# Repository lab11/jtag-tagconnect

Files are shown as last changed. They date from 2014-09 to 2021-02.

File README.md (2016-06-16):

JTAG to Tag Connect
===================

This PCB is an adapter that converts the [20 pin JLink](https://www.segger.com/jlink-debug-probes.html) connector to
a [6-pin Tag Connect](http://www.tag-connect.com/TC2030-IDC-NL),
much like [this](https://www.segger.com/jlink-6-pin-adapter.html) board.
Ours, however, additionally contains an onboard LDO
that can supply 3.3V to the attached device and the VTRef pin on the J-Link programmer
so that it can program boards that are not self powered.

Interface
---------

- **Switch 1**, labeled `VREF`: Set to `3V3` to connect the `VCC` pin on the TagConnect
header (and the attached board to be programmed) and the `VTRef` pin from
the Segger JLink to the 3.3 V output from the regulator.
Set to `DEV` to directly connect the `VTRef` pin on the JLink to the TagConnect
VCC pin. This sets the I/O voltage for the JLink, but does not power the target board.

- **Switch 2**, labeled `SWDIO`: This switch can connect the `SWDIO` and
`!RESET` signals, which is needed on some ICs. To leave the signals
disconnected, leave the switch in the empty (down) position.

Troubleshooting
---------------

1. Blue LED does not come on when attached to JLink.
You need to enable the 5 V output on the JLink:

        $ JlinkExe
        power on perm

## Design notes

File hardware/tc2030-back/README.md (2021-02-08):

# Tag Connect Clip Back

This is as replica / replacement for https://www.tag-connect.com/wp-content/uploads/bsk-pdf-manager/TC2030-CLIP_Datasheet_24.pdf

In addition to these boards, you'll need recepticle pins https://www.digikey.com/en/products/detail/mill-max-manufacturing-corp/0295-0-15-01-06-27-10-0/158170

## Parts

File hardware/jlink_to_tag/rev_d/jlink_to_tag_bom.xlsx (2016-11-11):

Qty | Value | Device | Package | Parts | Description | DIGIKEY
1 | 10nF | CAPACITOR0603_CAP | 0603_CAP | C1 | 0402 Capacitor | 490-1512-1-ND
2 | 4.7uF | CAPACITOR0603_CAP | 0603_CAP | C2, C3 | 0402 Capacitor | 490-3297-1-ND
9 | BLUE | LED-BLUE0603 | LED-0603 | D1, D2, D3, D4, D5, D6, D7, D8, D9 | Blue LEDs
1 |  | ML20 | ML20 | J1 | HARTING | S9172-ND
8 | JLINK_6PIN_TAG-CON | JLINK_6PIN_TAG-CON | 2X3_MALE_SHROUDED_0.100 | J2, J3, J4, J5, J6, J7, J8, J9 | This is a 6-pin Tag Connect header with the J-Link. | 3M15451-ND
1 |  | PINHD-2X3 | 2X03 | J10 | PIN HEADER
9 | 470 | RESISTOR0603-RES | 0603-RES | R1, R2, R3, R4, R5, R6, R7, R8, R9 | Resistor
7 | 1k | RESISTOR0603-RES | 0603-RES | R10, R11, R12, R13, R14, R15, R16 | Resistor | RHM1.00KHCT-ND
8 | PTS645SM43SMTR92 | PTS645SM43SMTR92 | PTS645 | S1, S2, S3, S4, S5, S6, S7, S8 | Tactile Switch SPST-NO Top Actuated Surface Mount | CKN9112CT-ND
1 | RM100772BCB | RM100772BCB | RM-SWITCH | S9 | Rotary Switch 8 Position SP7T 500mA (DC) 24VDC Through Hole | CKN10691-ND
8 | SN74AHC4066-RGY | SN74AHC4066-RGY | S-PVQFN-N14-3.5MM | S10, S11, S12, S13, S14, S15, S16, S17 |  | 296-15258-1-ND
2 | STS121PC04 | STS121PC04 | STS121PC04 | S18, S19 | Slide Switch SPDT Through Hole | 450-1609-ND
1 | 74HC4002PW | 74HC4002PW | TSSOP-14/5MM | U1 | NOR Gate IC 2 Channel 14-TSSOP | 568-8879-1-ND
1 | MAX8887EZK33+T | MAX8887EZK33+T | SOT-23-5 | U2 | IC REG LDO 3.3V 0.3A TSOT23-5 | MAX8887EZK33+TCT-ND

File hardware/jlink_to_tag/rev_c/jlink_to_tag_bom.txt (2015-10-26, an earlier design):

# Bill of Materials
# Converted from jlink_to_tag_bom.xlsx
# Generated by bom_to_text.py

Qty  Value               Device              Package                  Parts   Description                                          DIGIKEY
2    0.01uF              C-EUC0603           C0603                    C1, C2  CAPACITOR, European symbol                           490-1512-1-ND
1    10uF                CAP_POL1206         EIA3216                  C3      Capacitor Polarized                                  399-3684-1-ND
1    BLUE                LED-BLUE0603        LED-0603                 D1      Blue LEDs for production use                         
1                        ML20                ML20                     J1      HARTING                                              S9172-ND
1    JLINK_6PIN_TAG-CON  JLINK_6PIN_TAG-CON  2X3_MALE_SHROUDED_0.100  J2      This is a 6-pin Tag Connect header with the J-Link.  3M15451-ND
1    470                 RESISTOR0603-RES    0603-RES                 R1      Resistor                                             
1    EVQP2               EVQP2               EVQP2                    S1      SWITCH TACTILE SPST-NO 0.02A 15V                     P11084SCT-ND
2    TE_SSA12/SPDT       TE_SSA12/SPDT       TE_SSA12/SPDT            S2, S3  SWITCH SLIDE SPDT 2POS SSA SER                       450-1602-ND
1    LT1763CS8-3.3       LT1763CS8-3.3       SOIC8                    U1      500mA, Low Noise, LDO Micropower Regulators          LT1763CS8-3.3#TRPBFCT-ND

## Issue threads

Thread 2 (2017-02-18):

revD issues

ppannuto, 2017-02-18:
- [ ] active channel LEDs are too close to shrouded headers, hard to see, should move more towards the center of the board
 - [ ] reset buttons don't work if j-link isn't attached

ppannuto, 2017-02-18:
- [ ] board name isn't on board anywhere (which makes finding the appropriate repo an annoying game)

ppannuto, 2017-06-26:
- [ ] Center switch numbering is opposite of the external numbering (i.e. turning the switch counter-clockwise moves a slot forward clockwise)

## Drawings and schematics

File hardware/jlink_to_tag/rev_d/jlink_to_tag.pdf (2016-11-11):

# 20-Pin Ribbon Cable from JLink

# 6 Pin Pogo Connector

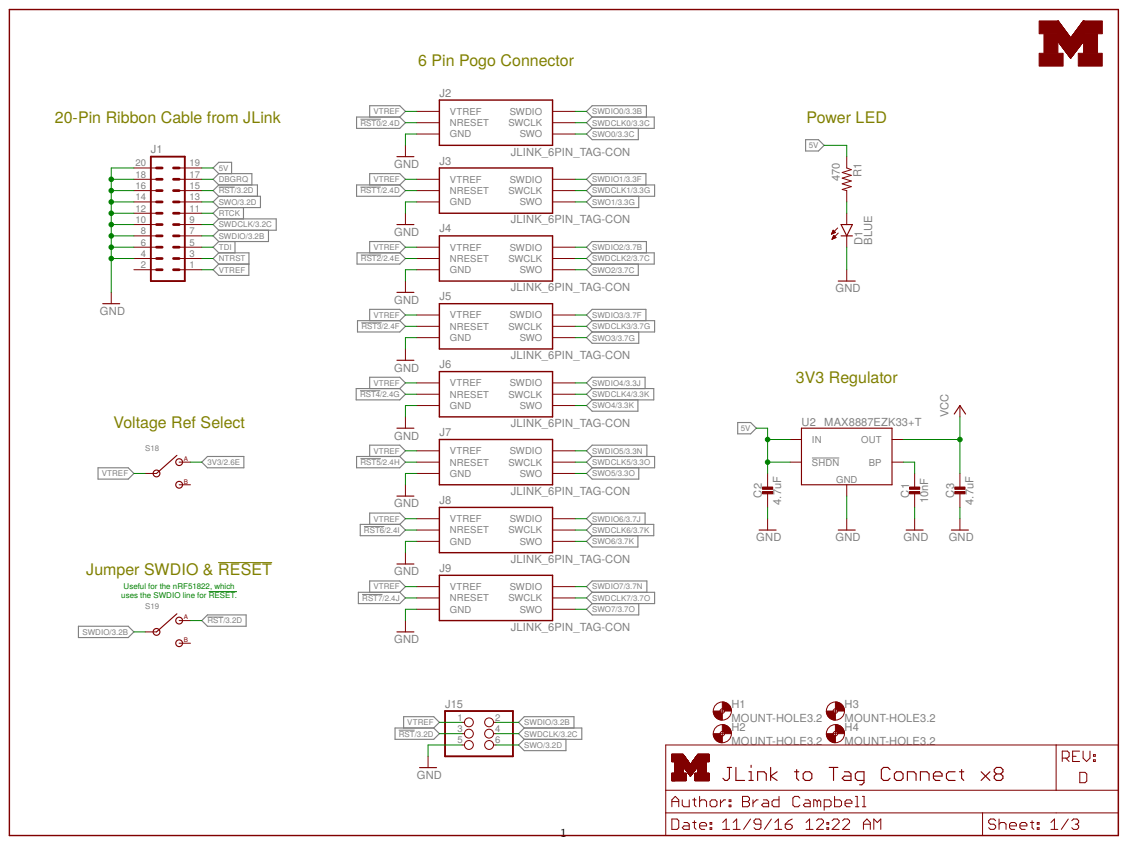
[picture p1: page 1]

Useful for the nRF51822, which
uses the SWDIO line for RESET.

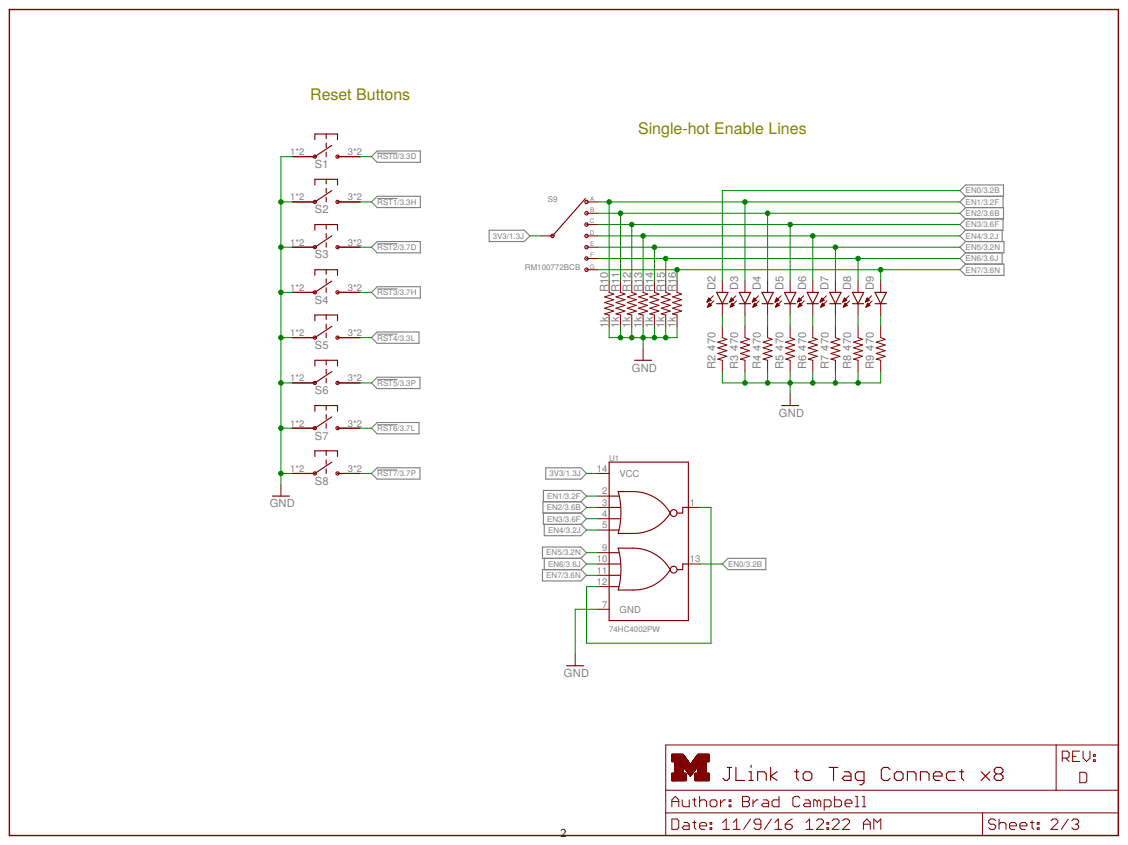
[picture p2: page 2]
Single-hot Enable Lines Reset Buttons GND; RM100772BCB; 1k1k1k1k1k1k1k GND; 470 470 470 470 470 470 470 470 GND 74HC4002PW GND S1 ¹*2; ABCD S9; EFG R¹⁰ R¹¹ R¹² R¹³ R¹⁴ R¹⁵ R¹⁶; 13 VCC 14; GND 7 U1 RST0/3.3D RST1/3.3H RST2/3.7D RST3/3.7H RST4/3.3L RST5/3.3P RST6/3.7L RST7/3.7P

# Tag Connect Port Enable Circuits

## GND

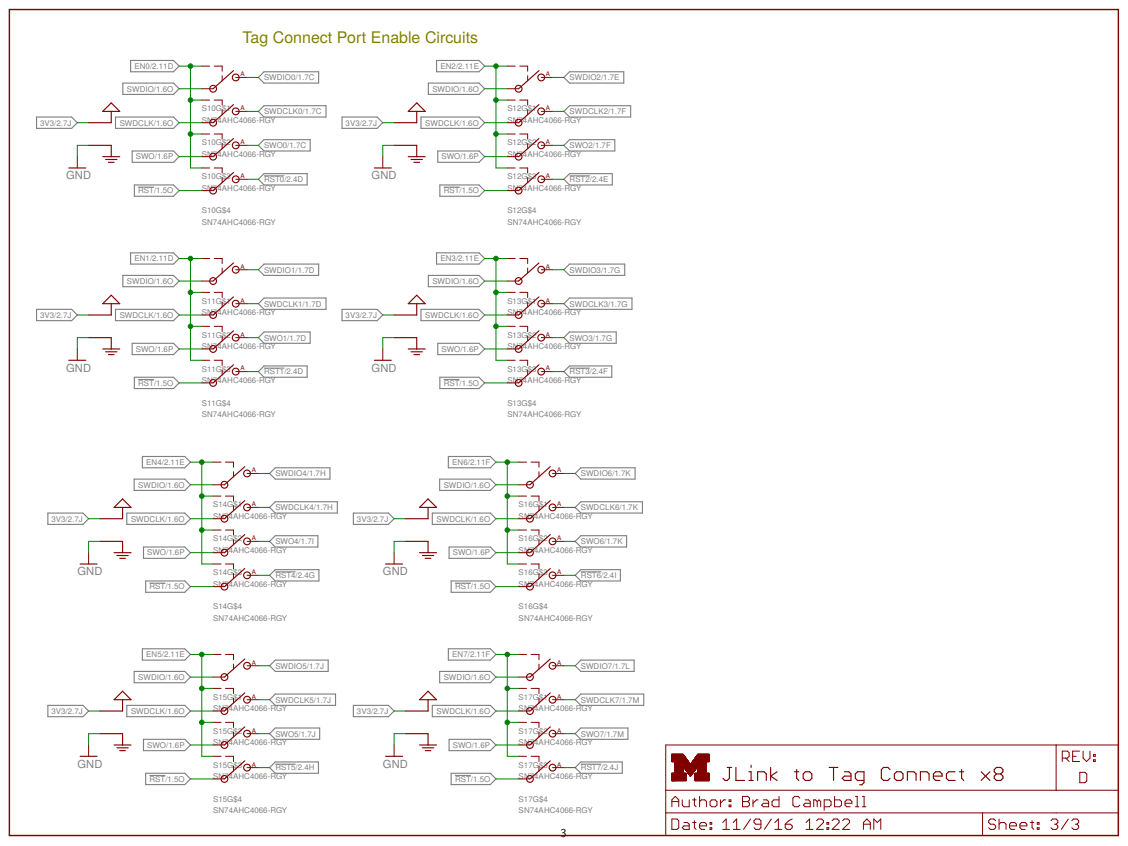
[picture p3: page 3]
SN74AHC4066-RGY; GND; SWDCLK/1.6O; SWO/1.6P; RST/1.5O; RST0/2.4D; SWO0/1.7C; SWDIO0/1.7C; SWDCLK0/1.7C; SWDIO/1.6O; RST1/2.4D; SWO1/1.7D; SWDCLK1/1.7D; SWDIO1/1.7D; SWDIO2/1.7E; SWDCLK2/1.7F SWO2/1.7F RST2/2.4E; SWDIO3/1.7G; SWDCLK3/1.7G; SWO3/1.7G; RST3/2.4F; SWDIO4/1.7H; SWDCLK4/1.7H; SWO4/1.7I RST4/2.4G; SWDIO5/1.7J SWDCLK5/1.7J SWO5/1.7J RST5/2.4H; SWDIO6/1.7K; SWDCLK6/1.7K; SWO6/1.7K RST6/2.4I; SWDIO7/1.7L SWDCLK7/1.7M; SWO7/1.7M; RST7/2.4J

### Top and Bottom Layers

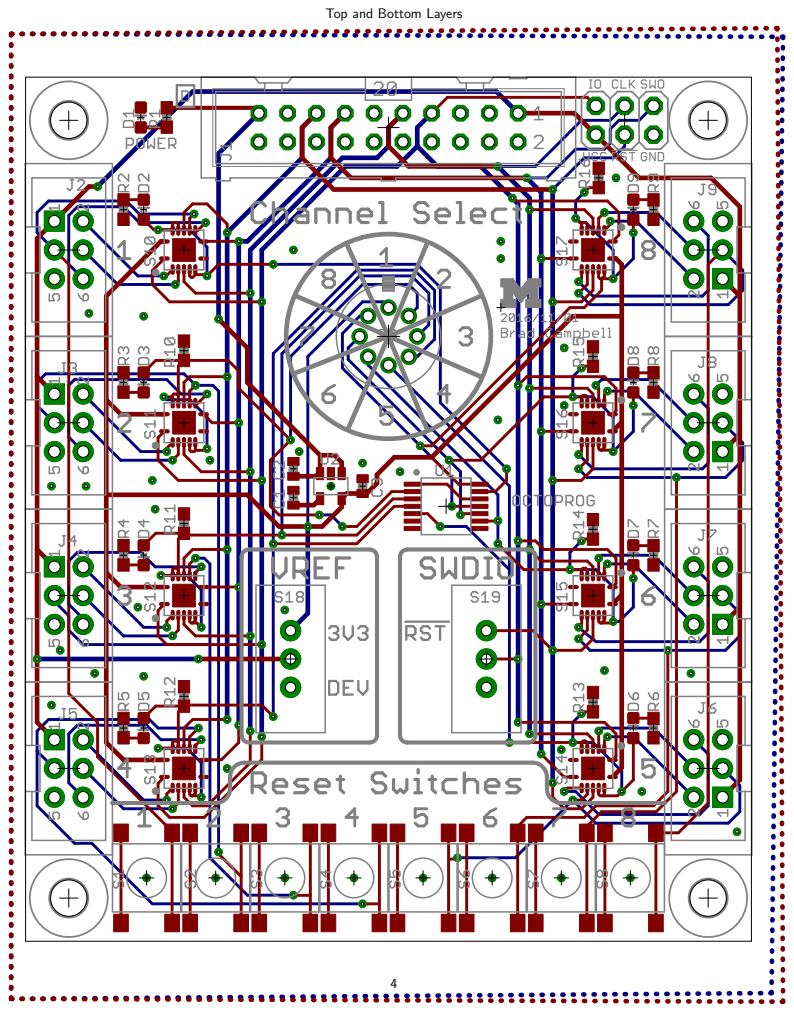
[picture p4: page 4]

### Top Layer

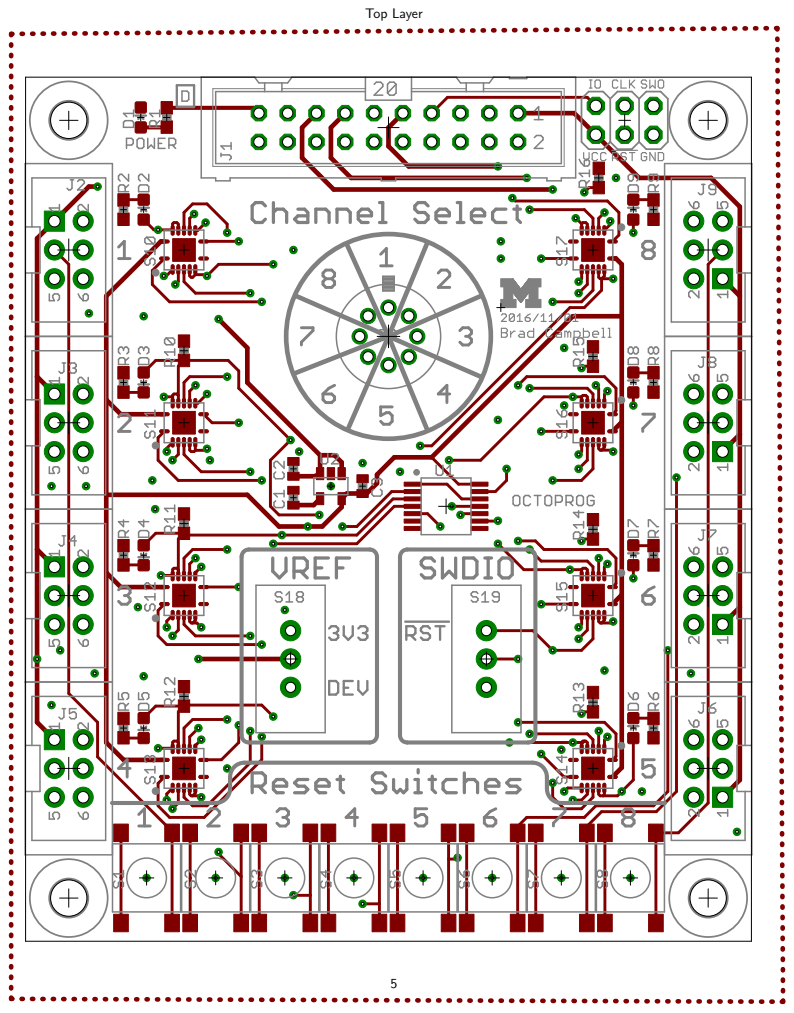
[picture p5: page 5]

### Bottom Layer

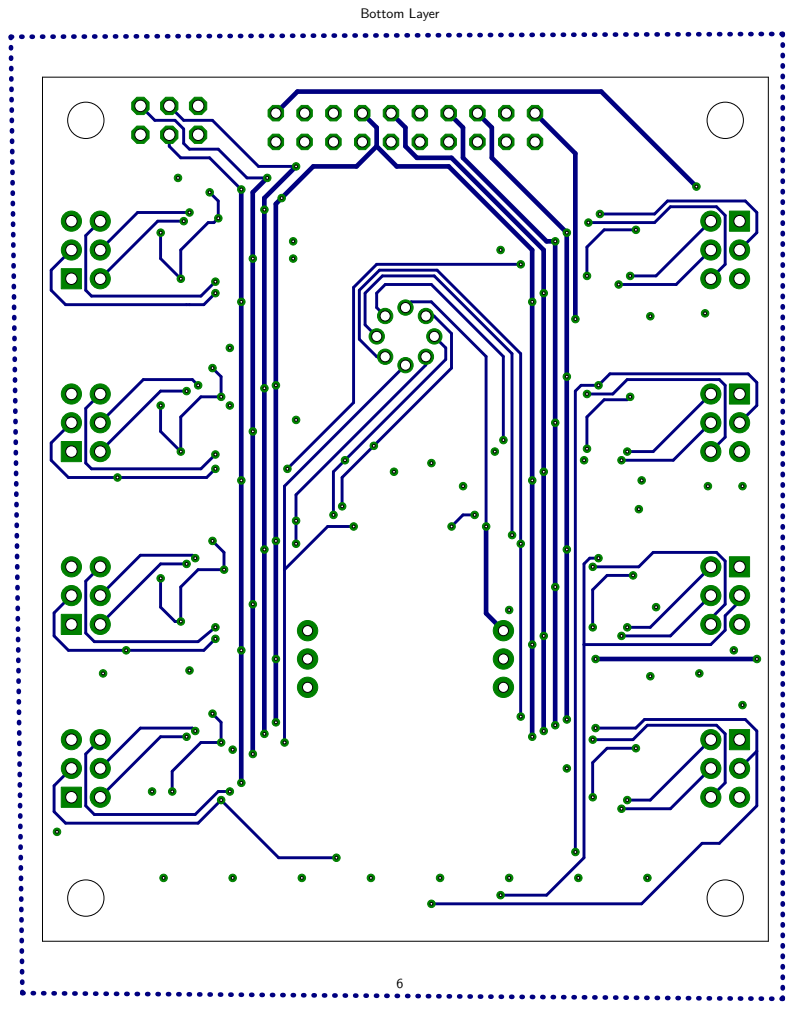
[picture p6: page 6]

### Top Copper Layer

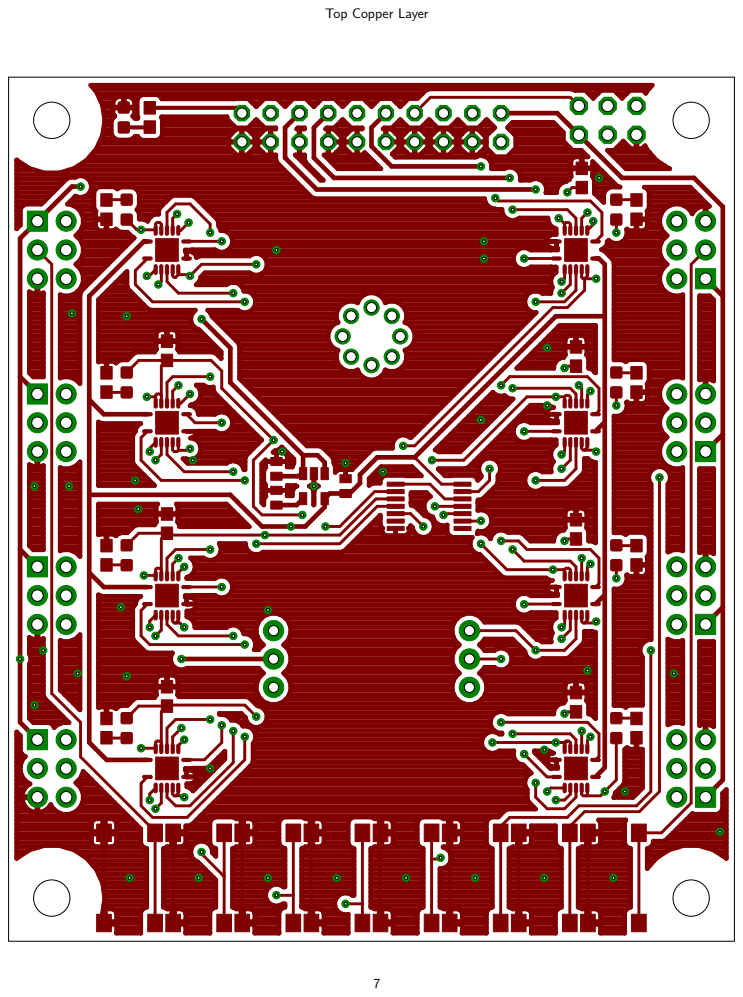
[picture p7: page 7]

### Bottom Copper Layer

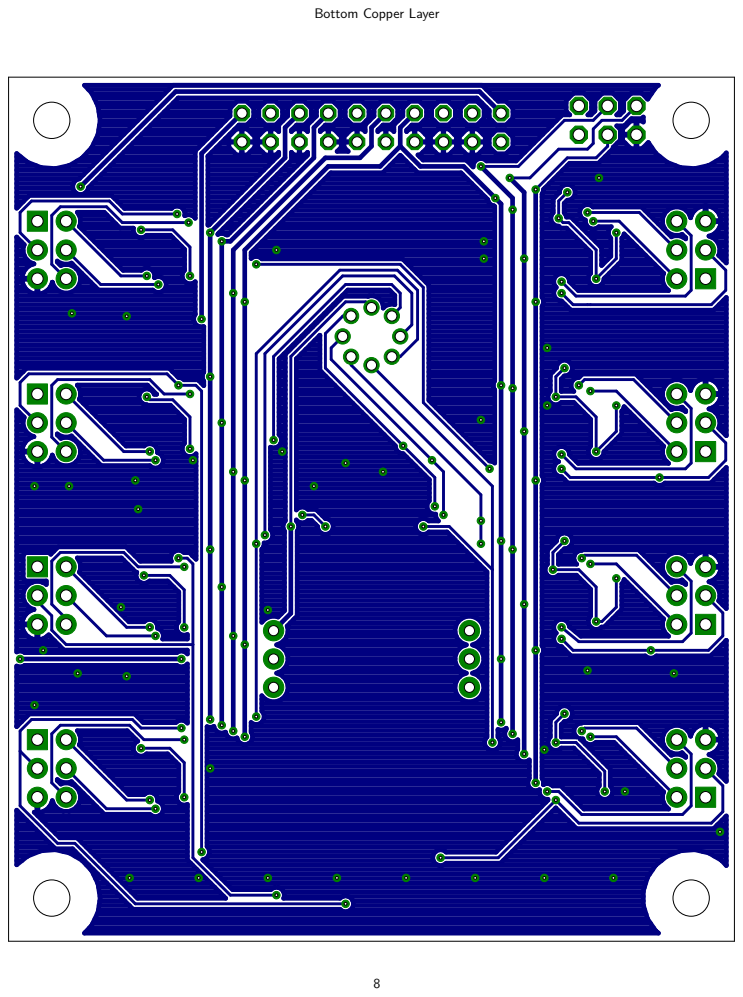
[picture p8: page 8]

### Top Paste Layer with Silkscreen

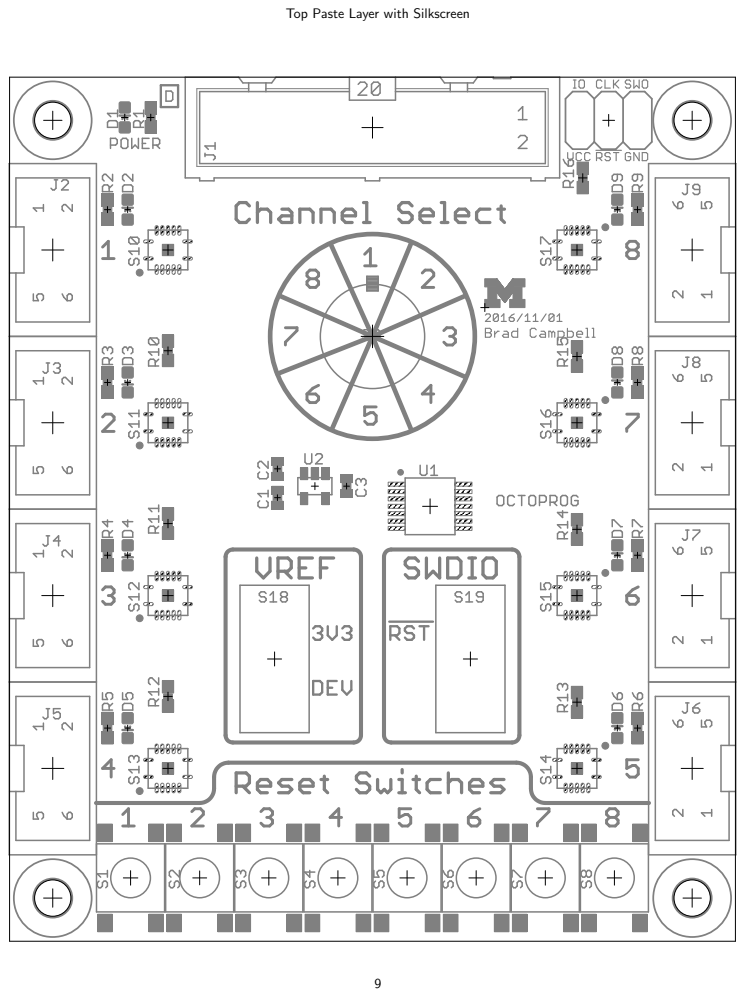
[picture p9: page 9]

### Bottom Paste Layer with Silkscreen

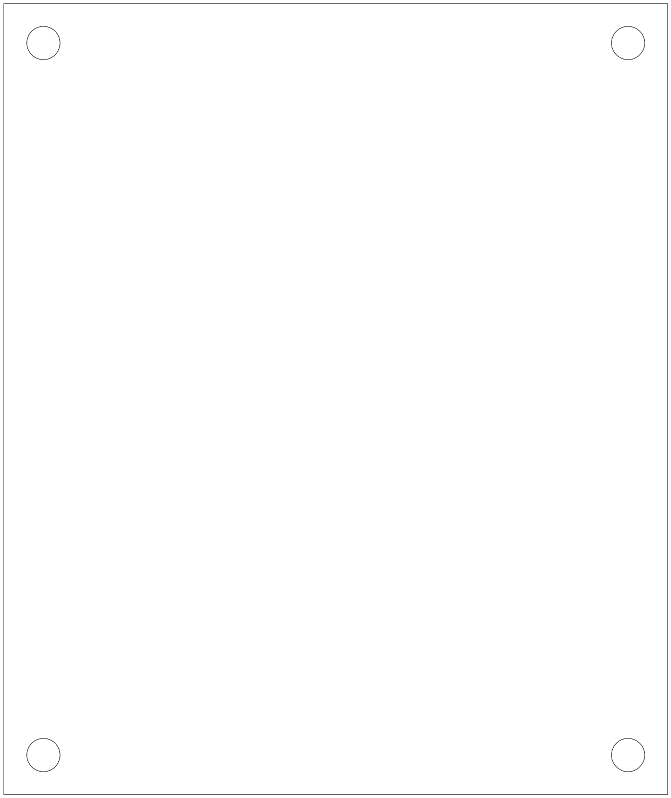
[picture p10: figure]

### Top and Bottom Layers 1:1 Scale

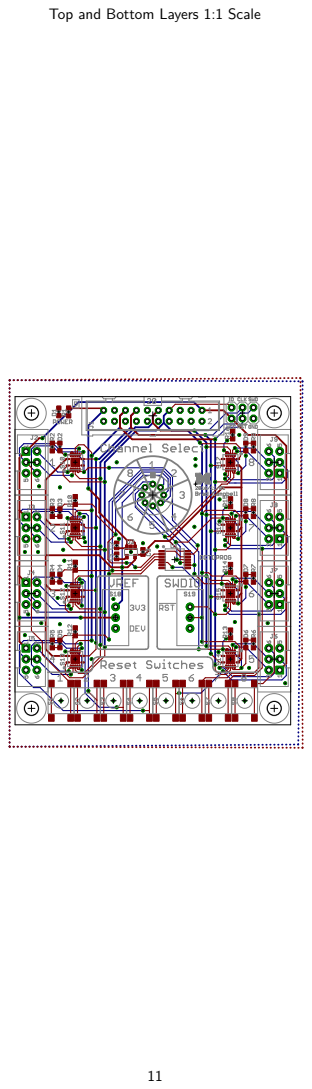
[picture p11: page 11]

### Top Layer 1:1 Scale

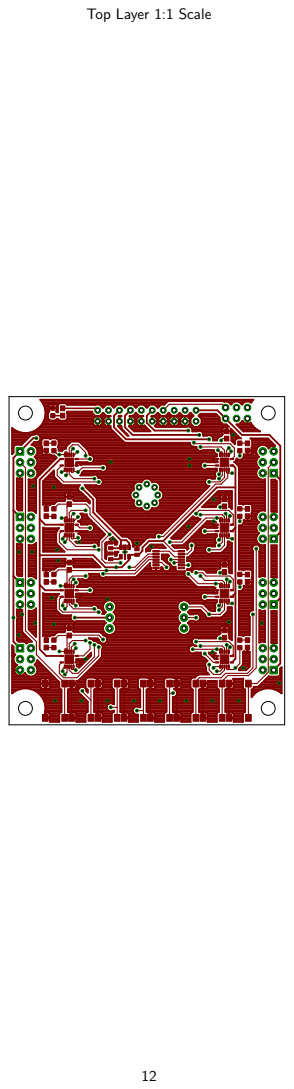
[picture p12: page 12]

### Bottom Copper Layer 1:1 Scale


# jlink_to_tag

Qty Value | Device | Package
1 10nF | CAPACITOR0603_CAP 0603_CAP
2 4.7uF | CAPACITOR0603_CAP 0603_CAP
9 BLUE | LED-BLUE0603 | LED-0603
1 | ML20 | ML20

## 8 JLINK_6PIN_TAG-CON JLINK_6PIN_TAG-CON 2X3_MALE_SHROUDED_0.100

1 | PINHD-2X3 | 2X03
9 470 | RESISTOR0603-RES | 0603-RES
7 1k | RESISTOR0603-RES | 0603-RES

## 8 PTS645SM43SMTR92 PTS645SM43SMTR92 PTS645

1 RM100772BCB | RM100772BCB | RM-SWITCH
8 SN74AHC4066-RGY | SN74AHC4066-RGY | S-PVQFN-N14-3.5MM
2 STS121PC04 | STS121PC04 | STS121PC04
1 74HC4002PW | 74HC4002PW | TSSOP-14/5MM
1 MAX8887EZK33+T | MAX8887EZK33+T | SOT-23-5

# jlink_to_tag

Parts | Description
C1 | 0402 Capacitor
C2, C3 | 0402 Capacitor
D1, D2, D3, D4, D5, D6, D7, D8, D9 | Blue LEDs
J1 | HARTING
J2, J3, J4, J5, J6, J7, J8, J9 | This is a 6-pin Tag Connect header with the J-Link.
J10 | PIN HEADER
R1, R2, R3, R4, R5, R6, R7, R8, R9 | Resistor
R10, R11, R12, R13, R14, R15, R16 | Resistor
S1, S2, S3, S4, S5, S6, S7, S8 | Tactile Switch SPST-NO Top Actuated Surface Mount
S9 | Rotary Switch 8 Position SP7T 500mA (DC) 24VDC Through Hole

## S10, S11, S12, S13, S14, S15, S16, S17

S18, S19 | Slide Switch SPDT Through Hole
U1 | NOR Gate IC 2 Channel 14-TSSOP
U2 | IC REG LDO 3.3V 0.3A TSOT23-5

# jlink_to_tag

## DIGIKEY

490-1512-1-ND
490-3297-1-ND

## S9172-ND 3M15451-ND

## RHM1.00KHCT-ND CKN9112CT-ND CKN10691-ND

296-15258-1-ND
450-1609-ND
568-8879-1-ND

## MAX8887EZK33+TCT-ND

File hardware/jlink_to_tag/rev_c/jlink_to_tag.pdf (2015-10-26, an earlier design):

20-Pin Ribbon Cable from JLink | 6 Pin Pogo Connector | Power LED

# TDI RTCK DBGRQ

Manual Reset; Voltage Ref Select; 3V3 Regulator; BLUE; GND; JLINK_6PIN_TAG-CON; EVQP2; TE_SSA12/SPDT; VTREF NRESET; SWO; SWCLK; SWDIO; OUT; SHDN; SENSE; 7 BYP; VTREF; NTRST; NRESET NRESET; NRESET; SWCLK/TCK; SWDIO/TMS; SWO/TDO

Jumper SWDIO & RESET

Useful for the nRF51822, which
uses the SWDIO line for RESET.


Top and Bottom Layers

Top Layer

Bottom Layer


Top Copper Layer


Bottom Copper Layer


Top Paste Layer with Silkscreen

Bottom Paste Layer with Silkscreen


Top and Bottom Layers 1:1 Scale

Top Layer 1:1 Scale


Bottom Copper Layer 1:1 Scale

### Sheet1

Qty Value | Device | Package | Parts
20.01uF | C-EUC0603 | C0603 | C1, C2
110uF | CAP_POL1206 | EIA3216 | C3
1 BLUE | LED-BLUE0603 | LED-0603 | D1
1 | ML20 | ML20 | J1
1JLINK_6PIN_TAG-CONJLINK_6PIN_TAG-CON2X3_MALE_SHROUDED_0.100J2
1470 | RESISTOR0603-RES 0603-RES | R1
1 EVQP2 | EVQP2 | EVQP2 | S1
2 TE_SSA12/SPDT | TE_SSA12/SPDT | TE_SSA12/SPDT | S2, S3
1LT1763CS8-3.3 | LT1763CS8-3.3 | SOIC8 | U1

### Sheet1

Description | DIGIKEY
CAPACITOR, European symbol | 490-1512-1-ND
Capacitor Polarized | 399-3684-1-ND
Blue LEDs for production use
HARTING | S9172-ND
This is a 6-pin Tag Connect header with the J-Link. 3M15451-ND Resistor
SWITCH TACTILE SPST-NO 0.02A 15V | P11084SCT-ND
SWITCH SLIDE SPDT 2POS SSA SER | 450-1602-ND
500mA, Low Noise, LDO Micropower RegulatorsLT1763CS8-3.3#TRPBFCT-ND

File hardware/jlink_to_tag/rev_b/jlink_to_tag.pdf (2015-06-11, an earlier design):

20-Pin Ribbon Cable from JLink | 6 Pin Pogo Connector | Power LED

# TDI RTCK DBGRQ

Manual Reset; Voltage Ref Select; 3V3 Regulator; BLUE; GND; JLINK_6PIN_TAG-CON; EVQP2; TE_SSA12/SPDT; SOLDERJUMPERNC2; VTREF NRESET; SWO; SWCLK; SWDIO; OUT; SHDN; SENSE; 7 BYP; VTREF; NTRST; NRESET NRESET; NRESET; SWCLK/TCK; SWDIO/TMS; SWO/TDO


Top and Bottom Layers

Top Layer

Bottom Layer


Top Copper Layer


Bottom Copper Layer


Top Paste Layer with Silkscreen

Bottom Paste Layer with Silkscreen


Top and Bottom Layers 1:1 Scale

Top Layer 1:1 Scale


Bottom Copper Layer 1:1 Scale

### Sheet1

Qty Value | Device | Package | Parts
20.01uF | C-EUC0603 | C0603 | C1, C2
110uF | CAP_POL1206 | EIA3216 | C3
1 BLUE | LED-BLUE0603 | LED-0603 | D1
1 | ML20 | ML20 | J1
1JLINK_6PIN_TAG-CONJLINK_6PIN_TAG-CON2X3_MALE_SHROUDED_0.100J2
1470 | RESISTOR0603-RES 0603-RES | R1
1 EVQP2 | EVQP2 | EVQP2 | S1
1 TE_SSA12/SPDT | TE_SSA12/SPDT | TE_SSA12/SPDT | S2
1LT1763CS8-3.3 | LT1763CS8-3.3 | SOIC8 | U1

### Sheet1

Description | DIGIKEY
CAPACITOR, European symbol | 490-1512-1-ND
Capacitor Polarized | 399-3684-1-ND
Blue LEDs for production use
HARTING | S9172-ND
This is a 6-pin Tag Connect header with the J-Link. 3M15451-ND Resistor
SWITCH TACTILE SPST-NO 0.02A 15V | P11084SCT-ND
SWITCH SLIDE SPDT 2POS SSA SER | 450-1602-ND
500mA, Low Noise, LDO Micropower RegulatorsLT1763CS8-3.3#TRPBFCT-ND

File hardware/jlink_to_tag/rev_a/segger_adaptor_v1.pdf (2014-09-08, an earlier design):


Is this the correct reset pin?


Top and Bottom Layers

Top Layer

Bottom Layer


Top Copper Layer


Bottom Copper Layer


Top Paste Layer with Silkscreen

Bottom Paste Layer with Silkscreen


Top and Bottom Layers 1:1 Scale

Top Layer 1:1 Scale


Bottom Copper Layer 1:1 Scale

### Sheet1

Qty Value | Device | Package | Parts
2 0.01uF | C-EUC0603 | C0603 | C1, C2
1 10uF | CAP_POL1206 | EIA3216 | C3
1 BLUE | LED-BLUE0603 | LED-0603 | D1
1 PINHD-2X5/0.050-NO7 PINHD-2X5/0.050-NO7 2X5-0.050-NO7 | J1
1 JLINK_6PIN_TAG-CON JLINK_6PIN_TAG-CON 2X3_MALE_SHROUDED_0.100 J2
1 | ML20 | ML20 | J3
1 | 470 RESISTOR0603-RES | 0603-RES | R1
1 LT1763CS8-3.3 | LT1763CS8-3.3 | SOIC8 | U1

### Sheet1

Description | DIGIKEY
CAPACITOR, European symbol | 490-1512-1-ND
Capacitor Polarized | 399-3684-1-ND
Blue LEDs for production use
| 609-3712-ND
This is a 6-pin Tag Connect header with the J-Link. 3M15451-ND
HARTING | S9172-ND
Resistor
500mA, Low Noise, LDO Micropower Regulators LT1763CS8-3.3#TRPBFCT-ND

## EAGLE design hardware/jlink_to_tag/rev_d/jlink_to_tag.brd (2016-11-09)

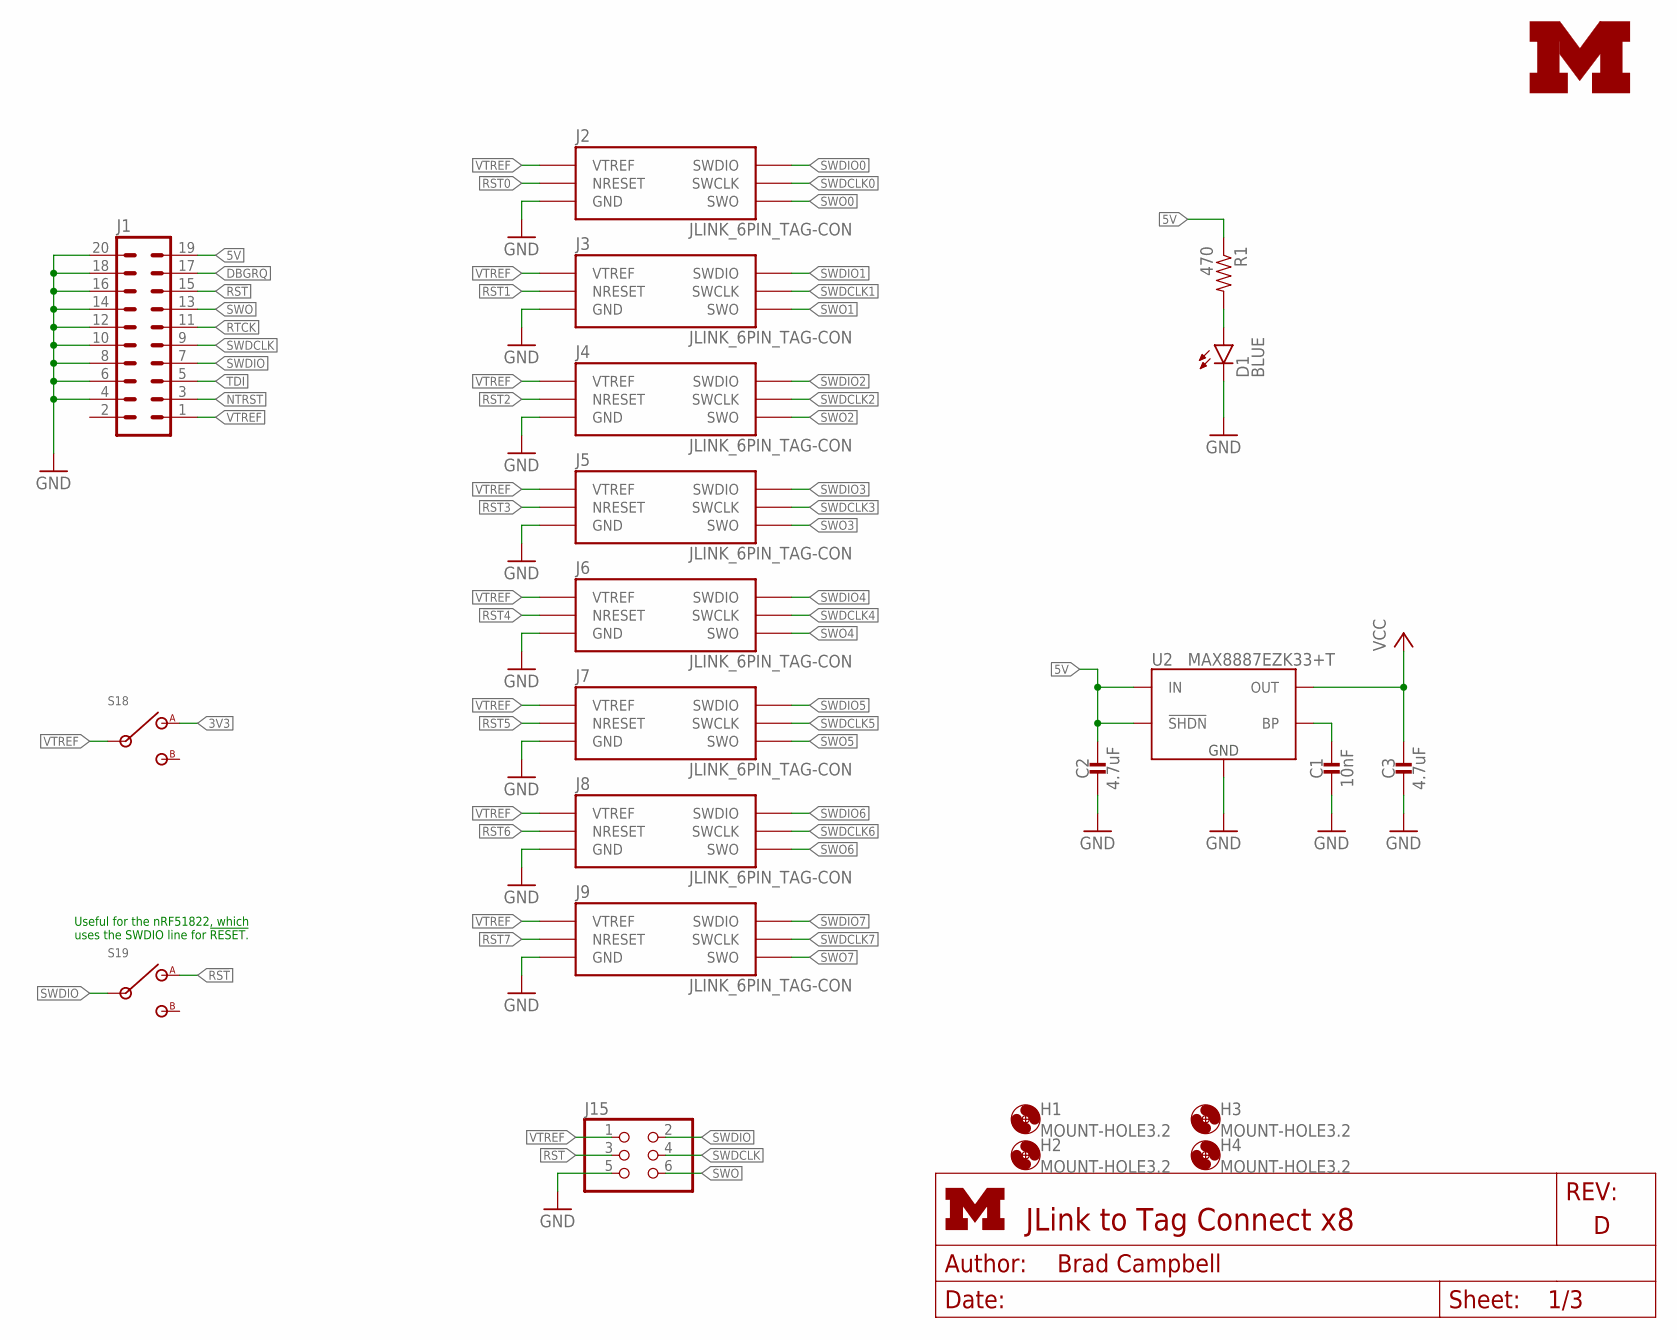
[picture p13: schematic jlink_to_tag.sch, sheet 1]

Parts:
C1: 10nF; 0603_CAP; DIGIKEY 490-1512-1-ND
C2, C3: 4.7uF; 0603_CAP; DIGIKEY 490-3297-1-ND
D1: BLUE; LED-0603
H1, H2, H3, H4: MOUNT-HOLE3.2; 3,2
J1: ML20; DIGIKEY S9172-ND
J2, J3, J4, J5, J6, J7, J8, J9: JLINK_6PIN_TAG-CON; 2X3_MALE_SHROUDED_0.100
J15: PINHD-2X3; 2X03
LOGO1: UMICH_SOLID_SMALL+; UMICH_SOLID_100MIL
R1: 470; 0603-RES
S18, S19: STS121PC04
U2: MAX8887EZK33+T; SOT-23-5

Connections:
3V3: C3.1, S18.1, U2.5 (OUT); also elsewhere on the board
5V: C2.1, J1.19, R1.1, U2.1 (IN), U2.3 (!SHDN)
!RST: J1.15, J15.3, S19.1; also elsewhere on the board
!RST0: J2.3 (NRESET); also elsewhere on the board
!RST1: J3.3 (NRESET); also elsewhere on the board
!RST2: J4.3 (NRESET); also elsewhere on the board
!RST3: J5.3 (NRESET); also elsewhere on the board
!RST4: J6.3 (NRESET); also elsewhere on the board
!RST5: J7.3 (NRESET); also elsewhere on the board
!RST6: J8.3 (NRESET); also elsewhere on the board
!RST7: J9.3 (NRESET); also elsewhere on the board
DBGRQ: J1.17
GND: C1.2, C2.2, C3.2, D1.C, J1.4, J1.6, J1.8, J1.10, J1.12, J1.14, J1.16, J1.18, J1.20, J2.5 (GND), J3.5 (GND), J4.5 (GND), J5.5 (GND), J6.5 (GND), J7.5 (GND), J8.5 (GND), J9.5 (GND), J15.5, U2.2 (GND); also elsewhere on the board
unnamed: C1.1, U2.4 (BP)
unnamed: D1.A, R1.2
NTRST: J1.3
RTCK: J1.11
SWDCLK: J1.9, J15.4; also elsewhere on the board
SWDCLK0: J2.4 (SWCLK); also elsewhere on the board
SWDCLK1: J3.4 (SWCLK); also elsewhere on the board
SWDCLK2: J4.4 (SWCLK); also elsewhere on the board
SWDCLK3: J5.4 (SWCLK); also elsewhere on the board
SWDCLK4: J6.4 (SWCLK); also elsewhere on the board
SWDCLK5: J7.4 (SWCLK); also elsewhere on the board
SWDCLK6: J8.4 (SWCLK); also elsewhere on the board
SWDCLK7: J9.4 (SWCLK); also elsewhere on the board
SWDIO: J1.7, J15.2, S19.2; also elsewhere on the board
SWDIO0: J2.2 (SWDIO); also elsewhere on the board
SWDIO1: J3.2 (SWDIO); also elsewhere on the board
SWDIO2: J4.2 (SWDIO); also elsewhere on the board
SWDIO3: J5.2 (SWDIO); also elsewhere on the board
SWDIO4: J6.2 (SWDIO); also elsewhere on the board
SWDIO5: J7.2 (SWDIO); also elsewhere on the board
SWDIO6: J8.2 (SWDIO); also elsewhere on the board
SWDIO7: J9.2 (SWDIO); also elsewhere on the board
SWO: J1.13, J15.6; also elsewhere on the board
SWO0: J2.6 (SWO); also elsewhere on the board
SWO1: J3.6 (SWO); also elsewhere on the board
SWO2: J4.6 (SWO); also elsewhere on the board
SWO3: J5.6 (SWO); also elsewhere on the board
SWO4: J6.6 (SWO); also elsewhere on the board
SWO5: J7.6 (SWO); also elsewhere on the board
SWO6: J8.6 (SWO); also elsewhere on the board
SWO7: J9.6 (SWO); also elsewhere on the board
TDI: J1.5
VTREF: J1.1, J2.1 (VTREF), J3.1 (VTREF), J4.1 (VTREF), J5.1 (VTREF), J6.1 (VTREF), J7.1 (VTREF), J8.1 (VTREF), J9.1 (VTREF), J15.1, S18.2

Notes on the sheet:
Useful for the nRF51822, which uses the SWDIO line for !RESET.

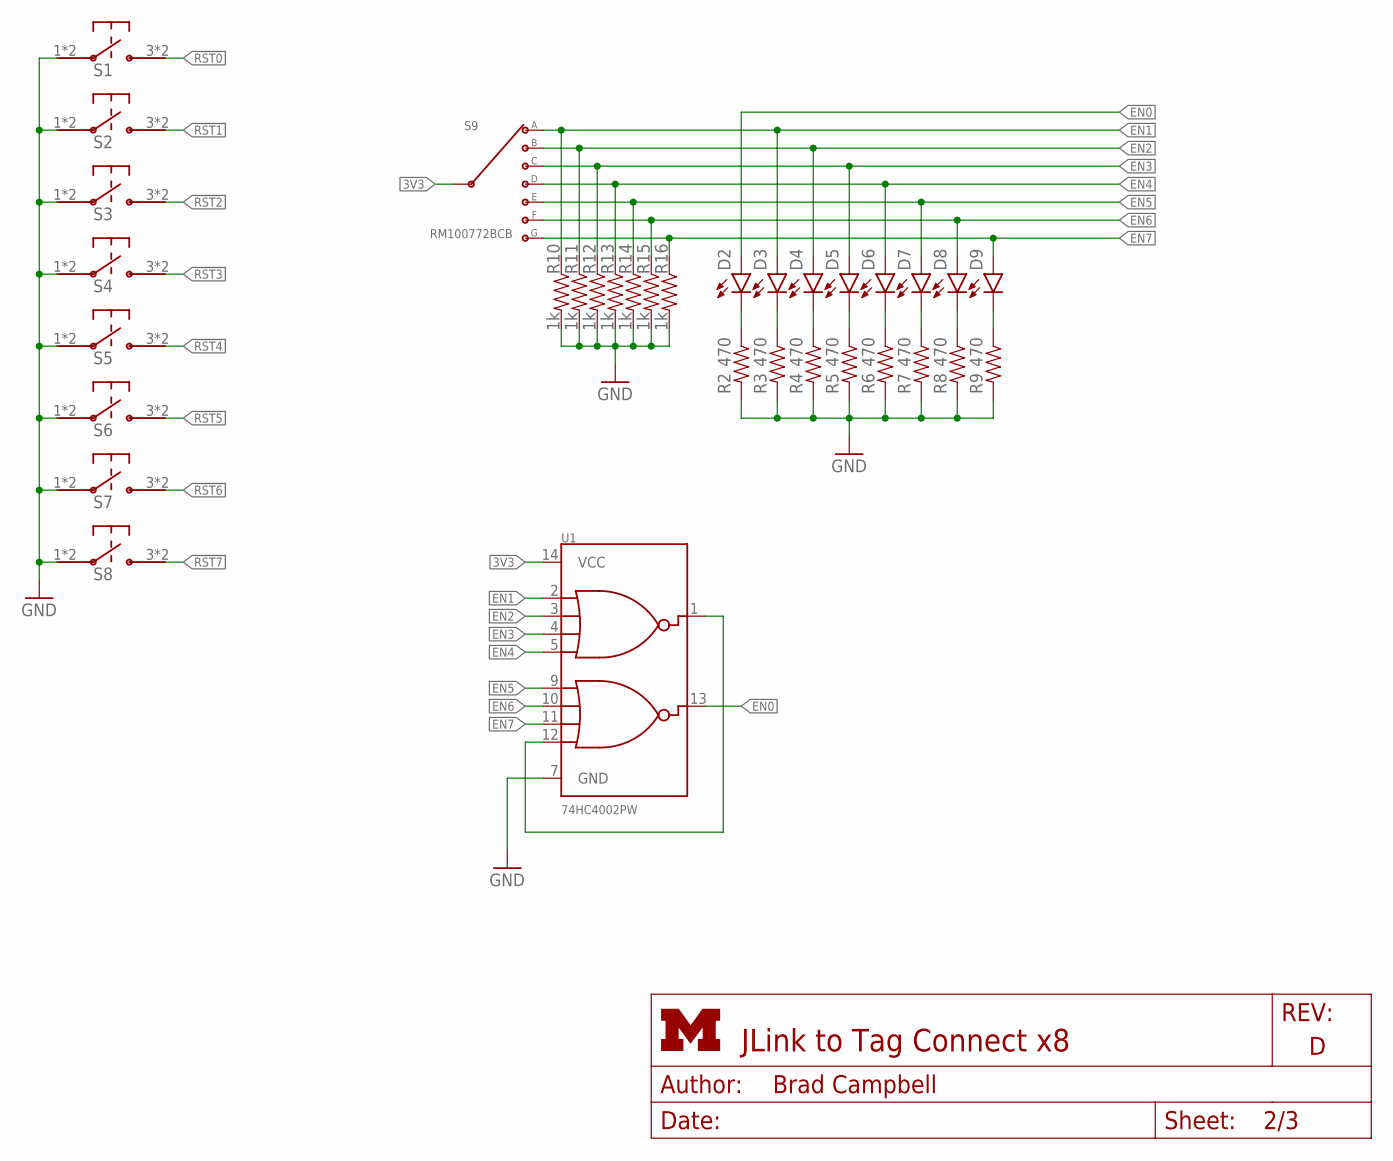
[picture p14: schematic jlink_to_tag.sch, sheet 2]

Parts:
D2, D3, D4, D5, D6, D7, D8, D9: BLUE; LED-0603
R2, R3, R4, R5, R6, R7, R8, R9: 470; 0603-RES
R10, R11, R12, R13, R14, R15, R16: 1k; 0603-RES
S1, S2, S3, S4, S5, S6, S7, S8: PTS645SM43SMTR92; PTS645
S9: RM100772BCB; RM-SWITCH
U1: 74HC4002PW; TSSOP-14/5MM

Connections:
3V3: S9.C (INPUT), U1.14 (VCC); also elsewhere on the board
!RST0: S1.3, S1.4; also elsewhere on the board
!RST1: S2.3, S2.4; also elsewhere on the board
!RST2: S3.3, S3.4; also elsewhere on the board
!RST3: S4.3, S4.4; also elsewhere on the board
!RST4: S5.3, S5.4; also elsewhere on the board
!RST5: S6.3, S6.4; also elsewhere on the board
!RST6: S7.3, S7.4; also elsewhere on the board
!RST7: S8.3, S8.4; also elsewhere on the board
EN0: D2.A, U1.13 (BOUT); also elsewhere on the board
EN1: D3.A, R10.1, S9.1 (A), U1.2 (A1); also elsewhere on the board
EN2: D4.A, R11.1, S9.2 (B), U1.3 (A2); also elsewhere on the board
EN3: D5.A, R12.1, S9.3 (C), U1.4 (A3); also elsewhere on the board
EN4: D6.A, R13.1, S9.4 (D), U1.5 (A4); also elsewhere on the board
EN5: D7.A, R14.1, S9.5 (E), U1.9 (B1); also elsewhere on the board
EN6: D8.A, R15.1, S9.6 (F), U1.10 (B2); also elsewhere on the board
EN7: D9.A, R16.1, S9.7 (G), U1.11 (B3); also elsewhere on the board
GND: R2.2, R3.2, R4.2, R5.2, R6.2, R7.2, R8.2, R9.2, R10.2, R11.2, R12.2, R13.2, R14.2, R15.2, R16.2, S1.1, S1.2, S2.1, S2.2, S3.1, S3.2, S4.1, S4.2, S5.1, S5.2, S6.1, S6.2, S7.1, S7.2, S8.1, S8.2, U1.7 (GND); also elsewhere on the board
unnamed: D2.C, R2.1
unnamed: D3.C, R3.1
unnamed: D4.C, R4.1
unnamed: D5.C, R5.1
unnamed: D6.C, R6.1
unnamed: D7.C, R7.1
unnamed: D8.C, R8.1
unnamed: D9.C, R9.1
unnamed: U1.1 (AOUT), U1.12 (B4)

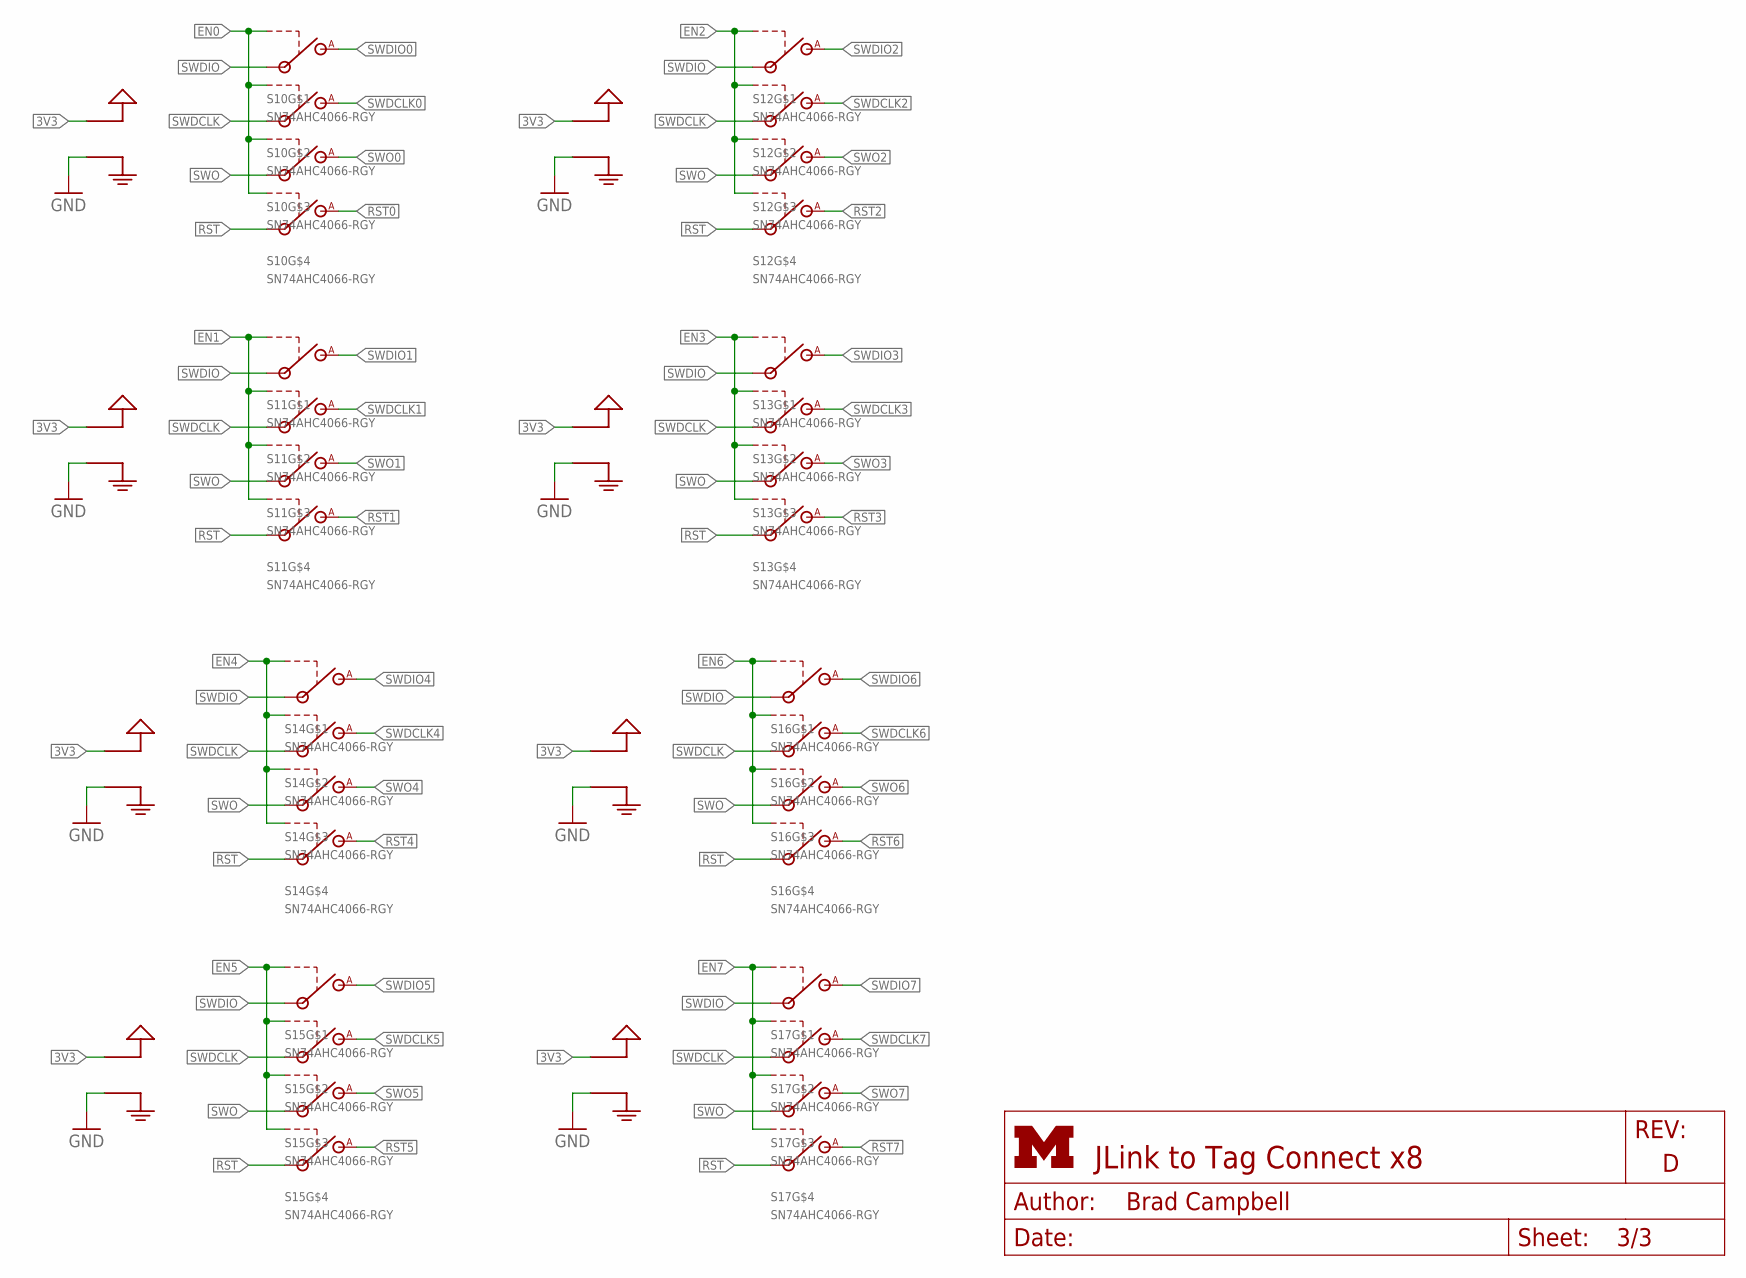
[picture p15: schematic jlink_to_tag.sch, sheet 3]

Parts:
S10, S11, S12, S13, S14, S15, S16, S17: SN74AHC4066-RGY; S-PVQFN-N14-3.5MM

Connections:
3V3: S10.14 (VCC), S11.14 (VCC), S12.14 (VCC), S13.14 (VCC), S14.14 (VCC), S15.14 (VCC), S16.14 (VCC), S17.14 (VCC); also elsewhere on the board
!RST: S10.11 (IN), S11.11 (IN), S12.11 (IN), S13.11 (IN), S14.11 (IN), S15.11 (IN), S16.11 (IN), S17.11 (IN); also elsewhere on the board
!RST0: S10.10 (A); also elsewhere on the board
!RST1: S11.10 (A); also elsewhere on the board
!RST2: S12.10 (A); also elsewhere on the board
!RST3: S13.10 (A); also elsewhere on the board
!RST4: S14.10 (A); also elsewhere on the board
!RST5: S15.10 (A); also elsewhere on the board
!RST6: S16.10 (A); also elsewhere on the board
!RST7: S17.10 (A); also elsewhere on the board
EN0: S10.5 (CTRL), S10.6 (CTRL), S10.12 (CTRL), S10.13 (CTRL); also elsewhere on the board
EN1: S11.5 (CTRL), S11.6 (CTRL), S11.12 (CTRL), S11.13 (CTRL); also elsewhere on the board
EN2: S12.5 (CTRL), S12.6 (CTRL), S12.12 (CTRL), S12.13 (CTRL); also elsewhere on the board
EN3: S13.5 (CTRL), S13.6 (CTRL), S13.12 (CTRL), S13.13 (CTRL); also elsewhere on the board
EN4: S14.5 (CTRL), S14.6 (CTRL), S14.12 (CTRL), S14.13 (CTRL); also elsewhere on the board
EN5: S15.5 (CTRL), S15.6 (CTRL), S15.12 (CTRL), S15.13 (CTRL); also elsewhere on the board
EN6: S16.5 (CTRL), S16.6 (CTRL), S16.12 (CTRL), S16.13 (CTRL); also elsewhere on the board
EN7: S17.5 (CTRL), S17.6 (CTRL), S17.12 (CTRL), S17.13 (CTRL); also elsewhere on the board
GND: S10.7 (GND), S11.7 (GND), S12.7 (GND), S13.7 (GND), S14.7 (GND), S15.7 (GND), S16.7 (GND), S17.7 (GND); also elsewhere on the board
SWDCLK: S10.4 (IN), S11.4 (IN), S12.4 (IN), S13.4 (IN), S14.4 (IN), S15.4 (IN), S16.4 (IN), S17.4 (IN); also elsewhere on the board
SWDCLK0: S10.3 (A); also elsewhere on the board
SWDCLK1: S11.3 (A); also elsewhere on the board
SWDCLK2: S12.3 (A); also elsewhere on the board
SWDCLK3: S13.3 (A); also elsewhere on the board
SWDCLK4: S14.3 (A); also elsewhere on the board
SWDCLK5: S15.3 (A); also elsewhere on the board
SWDCLK6: S16.3 (A); also elsewhere on the board
SWDCLK7: S17.3 (A); also elsewhere on the board
SWDIO: S10.1 (IN), S11.1 (IN), S12.1 (IN), S13.1 (IN), S14.1 (IN), S15.1 (IN), S16.1 (IN), S17.1 (IN); also elsewhere on the board
SWDIO0: S10.2 (A); also elsewhere on the board
SWDIO1: S11.2 (A); also elsewhere on the board
SWDIO2: S12.2 (A); also elsewhere on the board
SWDIO3: S13.2 (A); also elsewhere on the board
SWDIO4: S14.2 (A); also elsewhere on the board
SWDIO5: S15.2 (A); also elsewhere on the board
SWDIO6: S16.2 (A); also elsewhere on the board
SWDIO7: S17.2 (A); also elsewhere on the board
SWO: S10.8 (IN), S11.8 (IN), S12.8 (IN), S13.8 (IN), S14.8 (IN), S15.8 (IN), S16.8 (IN), S17.8 (IN); also elsewhere on the board
SWO0: S10.9 (A); also elsewhere on the board
SWO1: S11.9 (A); also elsewhere on the board
SWO2: S12.9 (A); also elsewhere on the board
SWO3: S13.9 (A); also elsewhere on the board
SWO4: S14.9 (A); also elsewhere on the board
SWO5: S15.9 (A); also elsewhere on the board
SWO6: S16.9 (A); also elsewhere on the board
SWO7: S17.9 (A); also elsewhere on the board

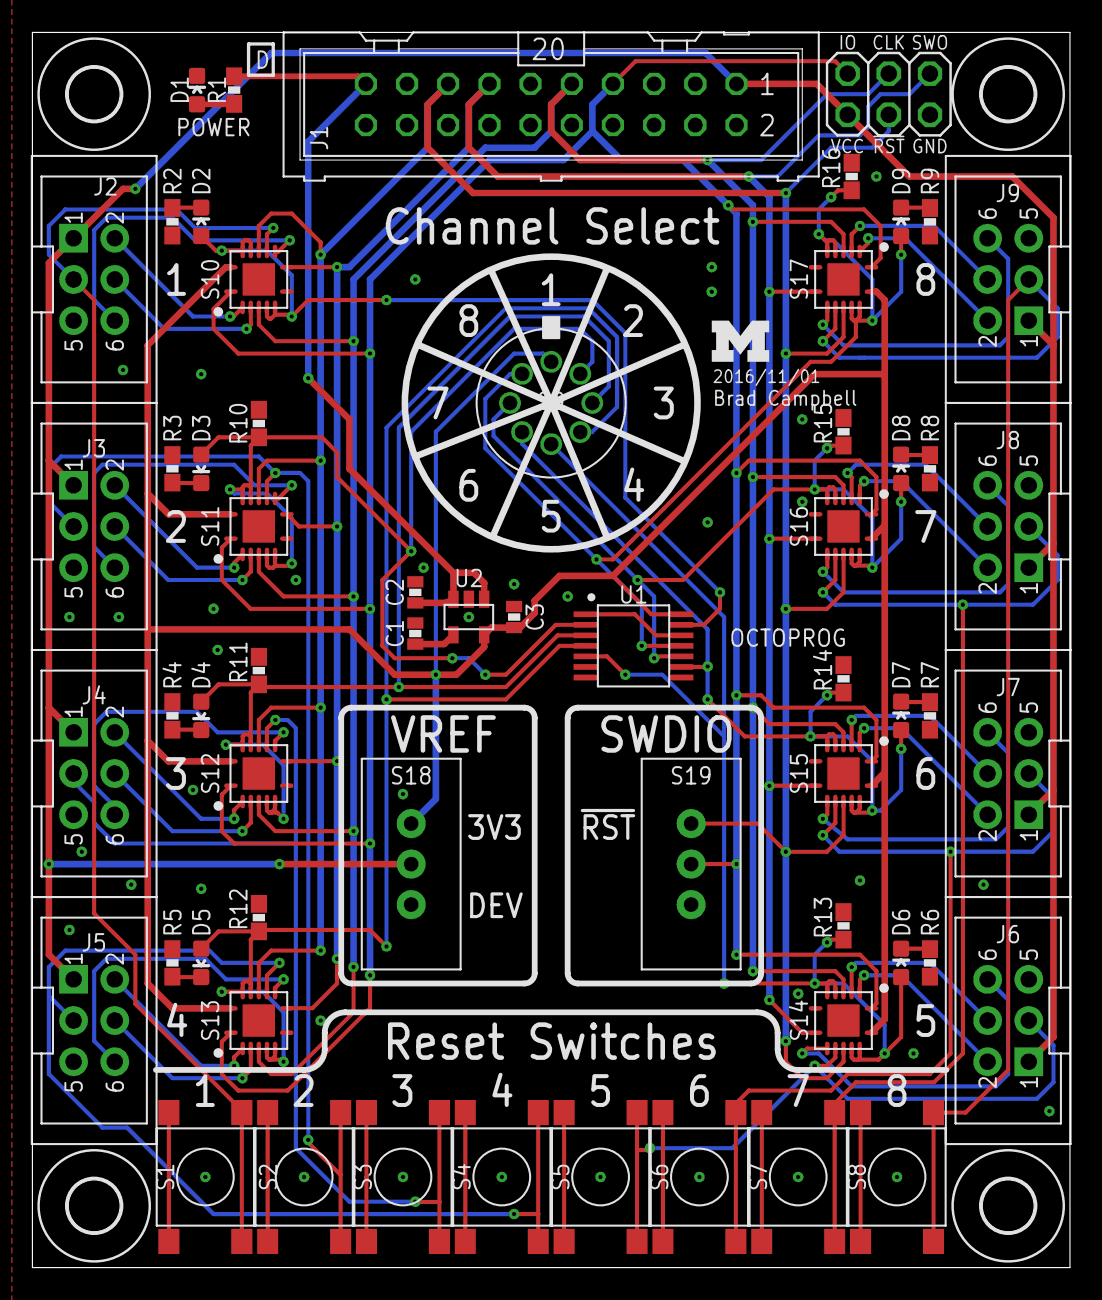
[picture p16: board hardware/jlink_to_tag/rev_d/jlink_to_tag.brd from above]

Board: 2 copper layers, 64.0 x 76.2 mm, 64 parts (0 on the bottom side), 59 nets.

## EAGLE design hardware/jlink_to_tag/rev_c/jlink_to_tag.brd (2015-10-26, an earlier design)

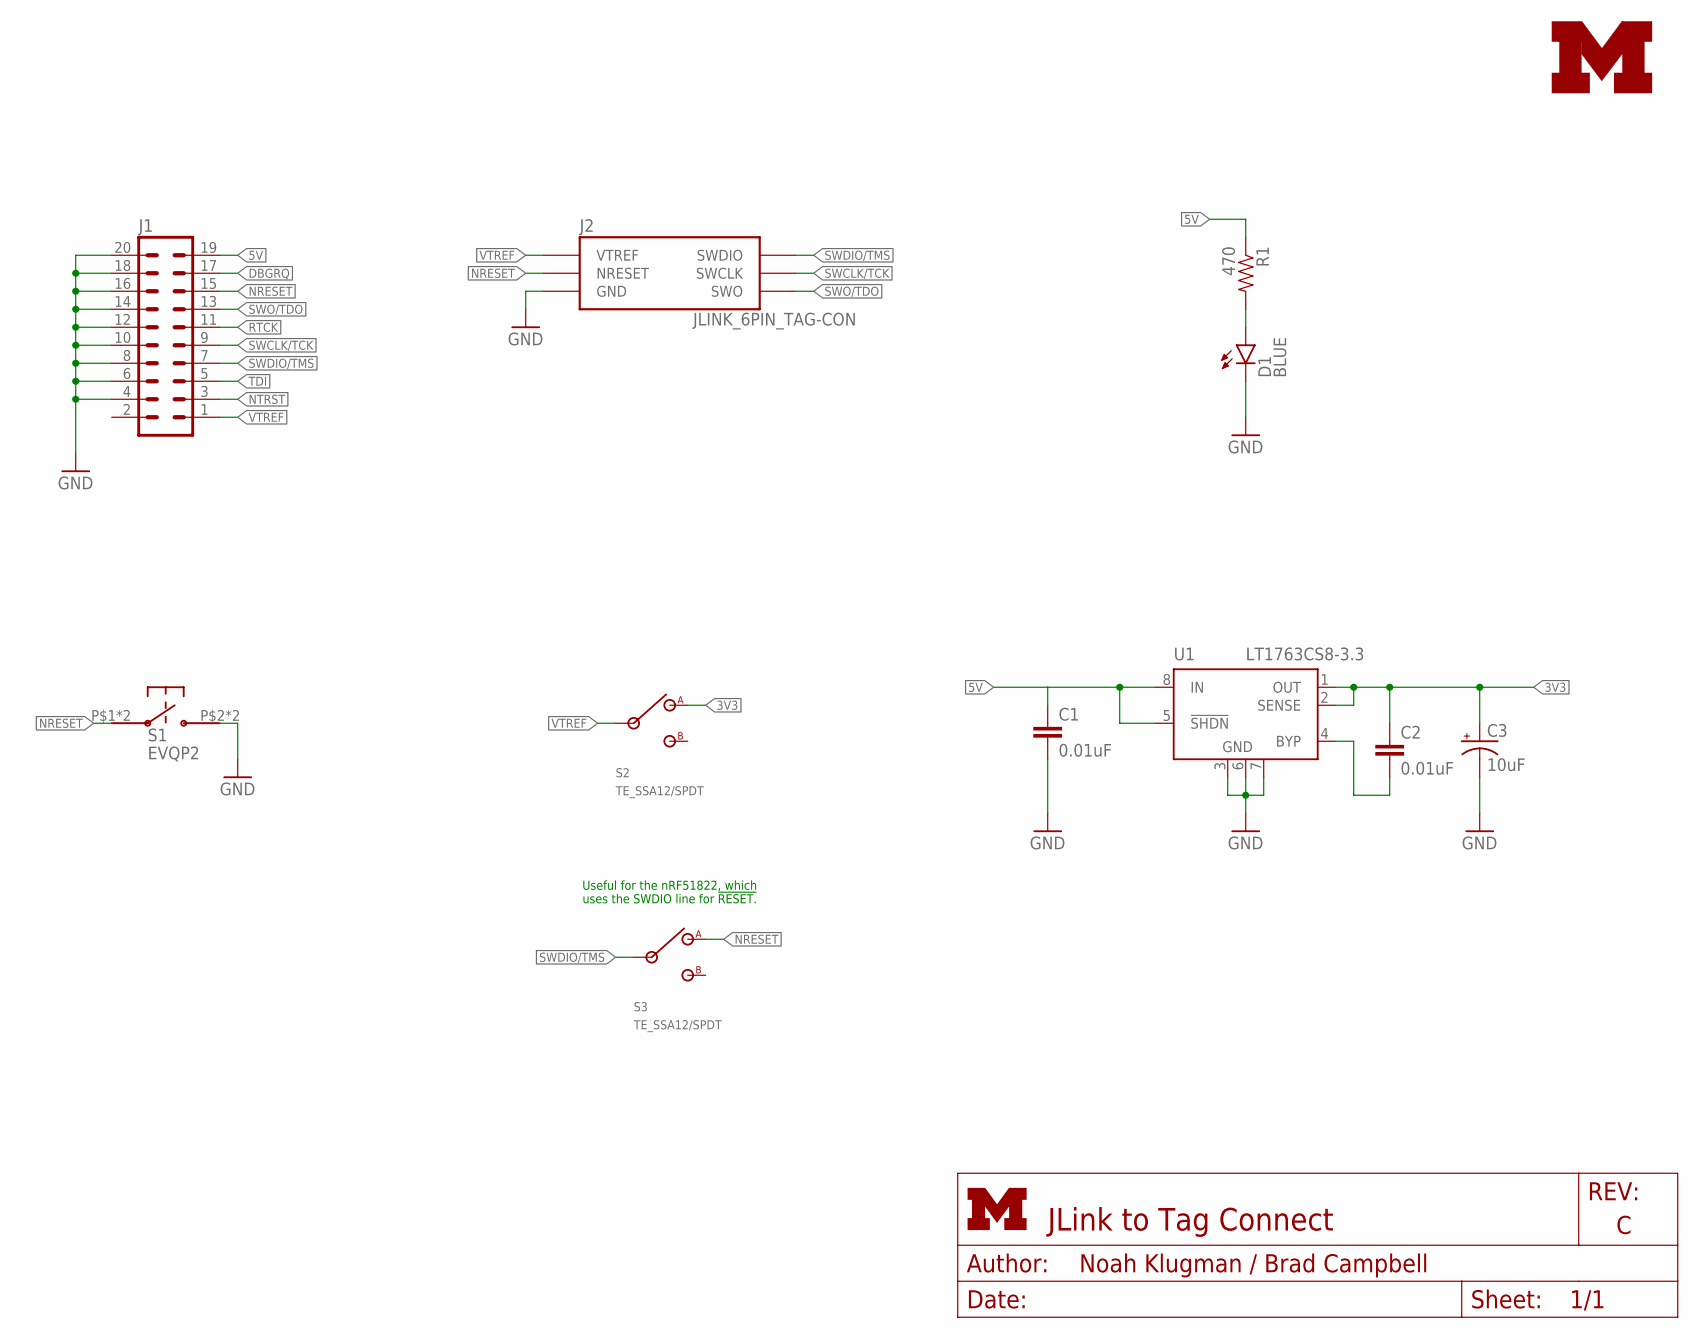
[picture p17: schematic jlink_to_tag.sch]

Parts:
C1, C2: 0.01uF; C0603; DIGIKEY 490-1512-1-ND
C3: 10uF; EIA3216; DIGIKEY 399-3684-1-ND
D1: BLUE; LED-0603
J1: ML20; DIGIKEY S9172-ND
J2: JLINK_6PIN_TAG-CON; 2X3_MALE_SHROUDED_0.100
LOGO1: UMICH_SOLID_SMALL+; UMICH_SOLID_100MIL
R1: 470; 0603-RES
S1: EVQP2
S2, S3: TE_SSA12/SPDT
U1: LT1763CS8-3.3; SOIC8; DIGIKEY LT1763CS8-3.3#TRPBFCT-ND

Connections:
3V3: C2.1, C3.A (+), S2.1 (A), U1.1 (OUT), U1.2 (SENSE)
5V: C1.1, J1.19, R1.1, U1.5 (!SHDN), U1.8 (IN)
DBGRQ: J1.17
GND: C1.2, C3.C (-), D1.C, J1.4, J1.6, J1.8, J1.10, J1.12, J1.14, J1.16, J1.18, J1.20, J2.5 (GND), S1.P$2, S1.P$4, U1.3 (GND), U1.6 (GND), U1.7 (GND)
unnamed: D1.A, R1.2
unnamed: C2.2, U1.4 (BYP)
NRESET: J1.15, J2.3 (NRESET), S1.P$1, S1.P$3, S3.1 (A)
NTRST: J1.3
RTCK: J1.11
SWCLK/TCK: J1.9, J2.4 (SWCLK)
SWDIO/TMS: J1.7, J2.2 (SWDIO), S3.IN
SWO/TDO: J1.13, J2.6 (SWO)
TDI: J1.5
VTREF: J1.1, J2.1 (VTREF), S2.IN

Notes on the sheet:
Useful for the nRF51822, which uses the SWDIO line for !RESET.

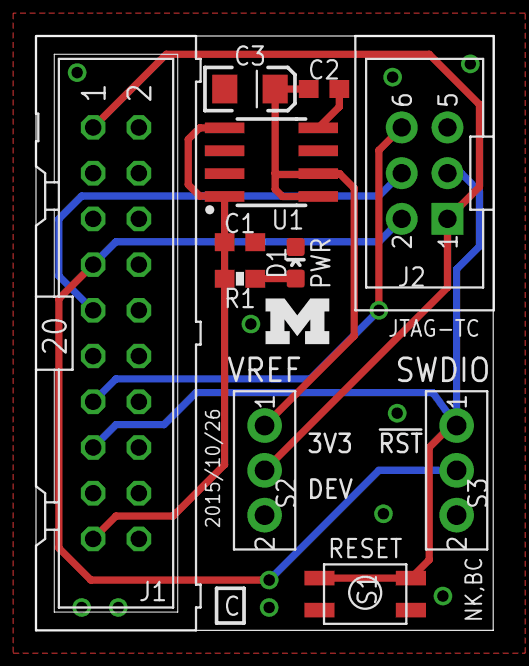
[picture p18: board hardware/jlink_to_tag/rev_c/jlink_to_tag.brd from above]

Board: 2 copper layers, 25.4 x 33.0 mm, 12 parts (0 on the bottom side), 10 nets.

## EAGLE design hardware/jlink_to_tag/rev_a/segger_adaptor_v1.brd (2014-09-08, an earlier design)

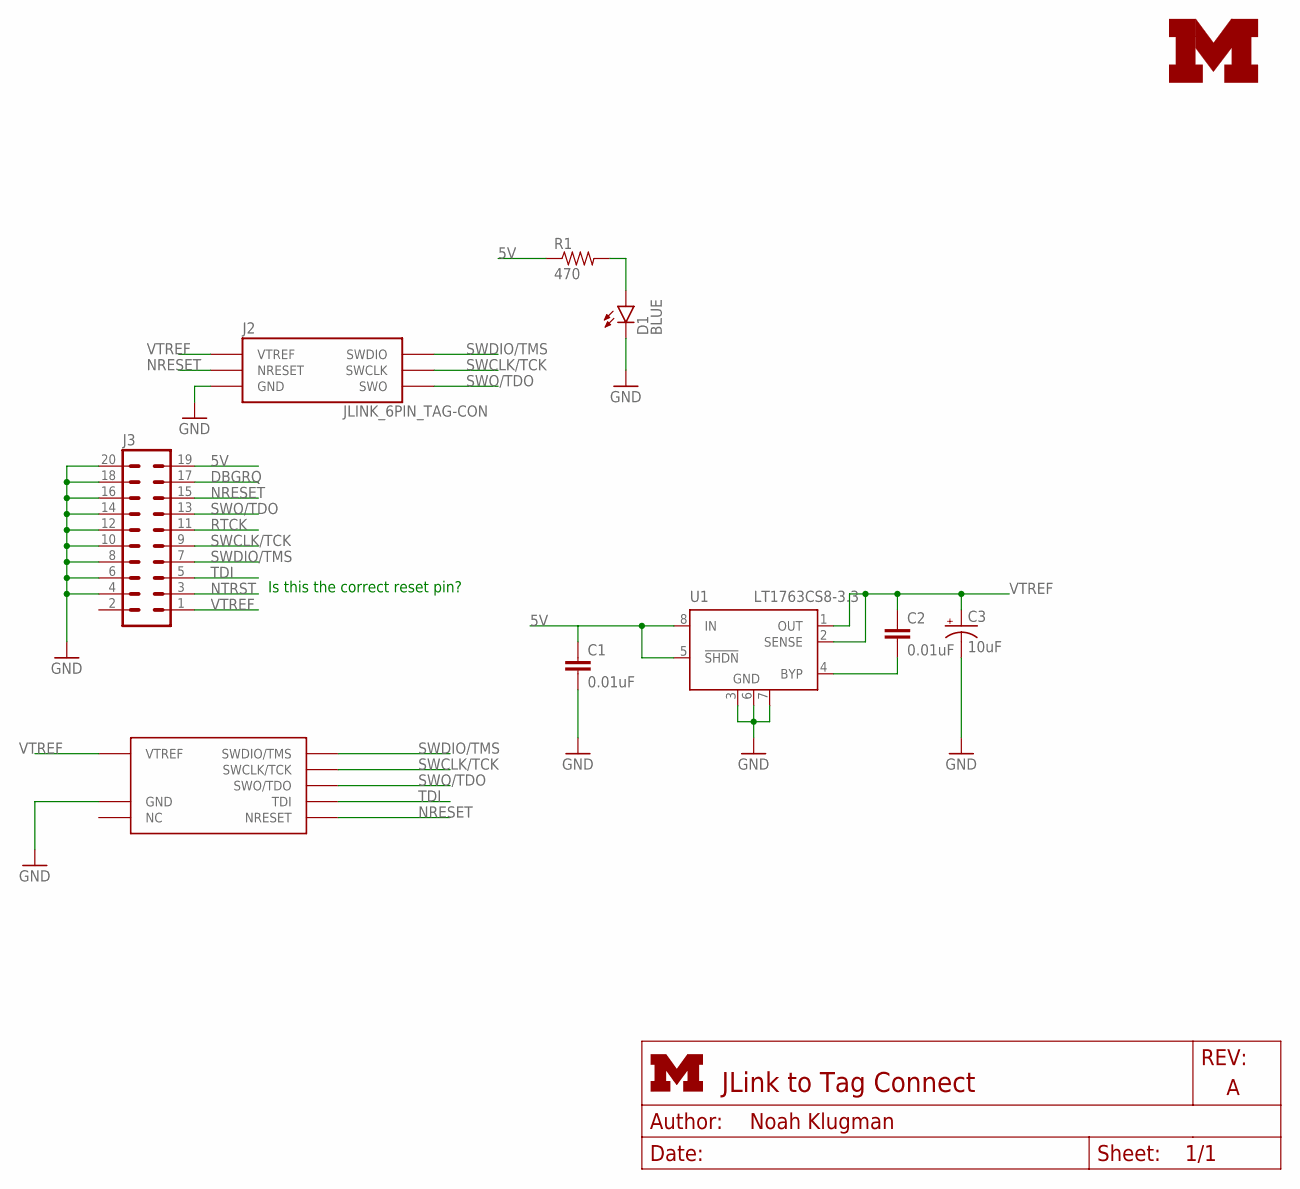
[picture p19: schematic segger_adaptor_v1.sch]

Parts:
C1, C2: 0.01uF; C0603; DIGIKEY 490-1512-1-ND
C3: 10uF; EIA3216; DIGIKEY 399-3684-1-ND
D1: BLUE; LED-0603
J1: PINHD-2X5/0.050-NO7; 2X5-0.050-NO7
J2: JLINK_6PIN_TAG-CON; 2X3_MALE_SHROUDED_0.100
J3: ML20; DIGIKEY S9172-ND
LOGO1: UMICH_SOLID_SMALL+; UMICH_SOLID_100MIL
R1: 470; 0603-RES
U1: LT1763CS8-3.3; SOIC8; DIGIKEY LT1763CS8-3.3#TRPBFCT-ND

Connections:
5V: C1.1, J3.19, R1.1, U1.5 (!SHDN), U1.8 (IN)
DBGRQ: J3.17
GND: C1.2, C3.C (-), D1.C, J1.GND@1 (GND), J1.GND@2 (GND), J2.5 (GND), J3.4, J3.6, J3.8, J3.10, J3.12, J3.14, J3.16, J3.18, J3.20, U1.3 (GND), U1.6 (GND), U1.7 (GND)
unnamed: D1.A, R1.2
unnamed: C2.2, U1.4 (BYP)
NRESET: J1.NRESET, J2.3 (NRESET), J3.15
NTRST: J3.3
RTCK: J3.11
SWCLK/TCK: J1.SWCLK/TCK, J2.4 (SWCLK), J3.9
SWDIO/TMS: J1.SWDIO/TMS, J2.2 (SWDIO), J3.7
SWO/TDO: J1.SWO/TDO, J2.6 (SWO), J3.13
TDI: J1.TDI, J3.5
VTREF: C2.1, C3.A (+), J1.VTREF, J2.1 (VTREF), J3.1, U1.1 (OUT), U1.2 (SENSE)

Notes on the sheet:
Is this the correct reset pin?

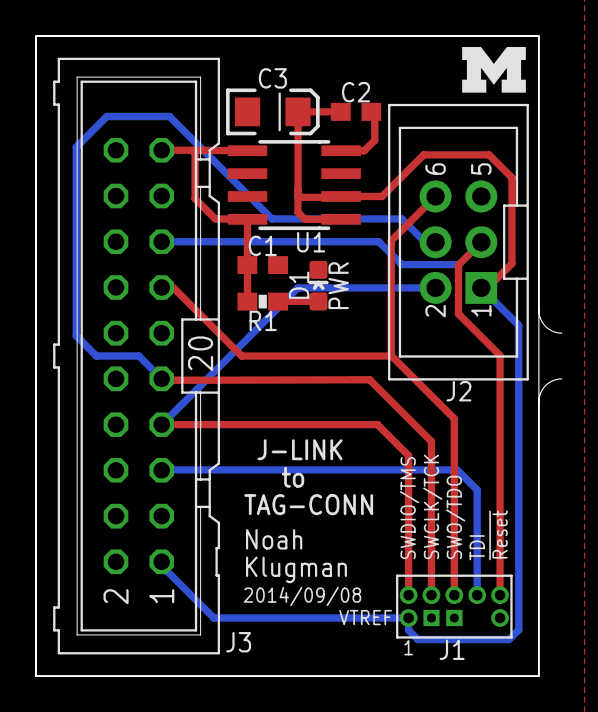
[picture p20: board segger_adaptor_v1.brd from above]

Board: 2 copper layers, 29.2 x 35.6 mm, 10 parts (0 on the bottom side), 10 nets.

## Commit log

2014-09-08 adding in the segger board
    [segger_adaptor_v1.brd, segger_adaptor_v1.sch]
2014-09-08 oops... wrong boards...
    [segger_adaptor_v1.brd, segger_adaptor_v1.sch]
2014-09-08 updates to adapter board
    [segger_adaptor_v1.brd, segger_adaptor_v1.sch]
2014-09-08 added docs for board
    [segger_adaptor_v1_bom.csv, segger_adaptor_v1_bom.xlsx]
2015-02-11 update folder structure
    [segger_adaptor_v1.brd, segger_adaptor_v1.sch, segger_adaptor_v1_bom.csv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]
2015-02-11 rev b of jlink to tag connect
    new:
    - switch to select if you want to use the regulator or let the
    device set vtref
    - reset button
    [jlink_to_tag.brd, jlink_to_tag.sch, jlink_to_tag_bom.xlsx]
2015-02-11 changed silkscreen
    [jlink_to_tag.brd]
2015-06-11 bug fixes to rev b
    [jlink_to_tag.brd, jlink_to_tag.sch, jlink_to_tag_bom.csv]
2015-09-05 tag connect board
    [tc2030-back.brd]
2015-10-24 added rev c with new switch
    can now toggle between version that works for nrf and for other arm
    chips
    [jlink_to_tag.brd, jlink_to_tag.sch, jlink_to_tag_bom.xlsx]
2015-10-24 update readme
    this board works for more than just nrf chips
2015-10-24 revert rev b to the version that was fabbed
    [jlink_to_tag.brd, jlink_to_tag.sch]
2015-10-24 1x1.3 inches
    [jlink_to_tag.brd]
2015-10-26 add output for jtag to tagconnect rev c
    [jlink_to_tag.brd, jlink_to_tag_bom.csv]
2016-10-31 jlink TIMES 8!!
    [jlink_to_tag.brd, jlink_to_tag.sch]
2016-11-01 getting more traces in
    [jlink_to_tag.brd, jlink_to_tag.sch]
2016-11-02 board layout
    [jlink_to_tag.brd, jlink_to_tag.sch]
2016-11-09 started renumber rev d
    [jlink_to_tag.brd, jlink_to_tag.sch]
2016-11-09 Order switches
    [jlink_to_tag.brd, jlink_to_tag.sch]
2016-11-09 add bom
    [jlink_to_tag_bom.xlsx]
2016-11-11 added zips
    [jlink_to_tag_bom.xlsx]
2021-02-04 add some more logos; round the corners
    [tc2030-back.brd]
2021-02-05 lower logo resolutions for CAM
    [tc2030-back.brd]

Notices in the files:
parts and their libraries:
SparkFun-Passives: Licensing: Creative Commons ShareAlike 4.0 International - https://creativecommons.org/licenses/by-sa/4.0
